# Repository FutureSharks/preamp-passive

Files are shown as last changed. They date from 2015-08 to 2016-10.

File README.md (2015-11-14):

# Preamp - Passive

This is the Arduino code, PCB layouts and 3D drawings for a HiFi passive preamplifier. It has the following features:

  * Volume control and input selection via encoder and Apple remote.
  * Uses a 256 step R2R relayed based attenuator.
  * Completely passive.
  * Only 5V power required.
  * [Adafruit NeoPixel](http://www.adafruit.com/category/168) shows volume level with colour.
  * Sleep mode with low power consumption: 0.9W.

Full build details can be found here:
http://www.diyaudio.com/forums/analog-line-level/275446-passive-preamp-arduino-based-remote-control-relay-r2r-input-selection.html

## Hardware

  * [MCP23S17](http://www.microchip.com/wwwproducts/Devices.aspx?product=MCP23S17): Controlled via SPI. This is the R2R relayed attenuator and controls the volume.
  * [MCP23S08](http://www.microchip.com/wwwproducts/Devices.aspx?product=MCP23S08): Controlled via SPI. For the input selector and mute.
  * [Adafruit NeoPixel](http://www.adafruit.com/category/168): Controlled via a single-wire control protocol.
  * IR sensor: Standard 38Khz type.
  * [Bourns EM14](https://www.bourns.com/pdfs/em14.pdf) Rotary Optical Encoder with switch.
  * [Modushop Galaxy Maggiorato GX187](http://www.modu.it/galaxyeng.html) with custom machined front and rear.

PCB and schematics are provided in EAGLE PCB format.

Front and rear panel 3D drawings are in AutoCAD format.

The IRremote library is from here:
https://github.com/z3t0/Arduino-IRremote

Adafruit NeoPixel library is from here:
https://github.com/adafruit/Adafruit_NeoPixel

## Photos

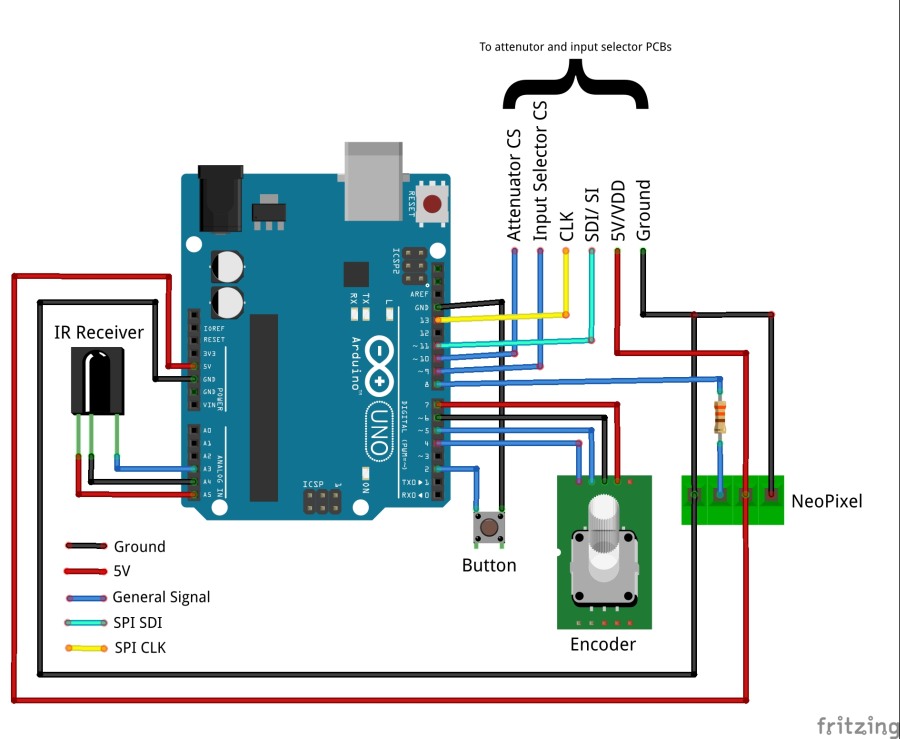
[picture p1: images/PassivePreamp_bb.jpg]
Connection diagram


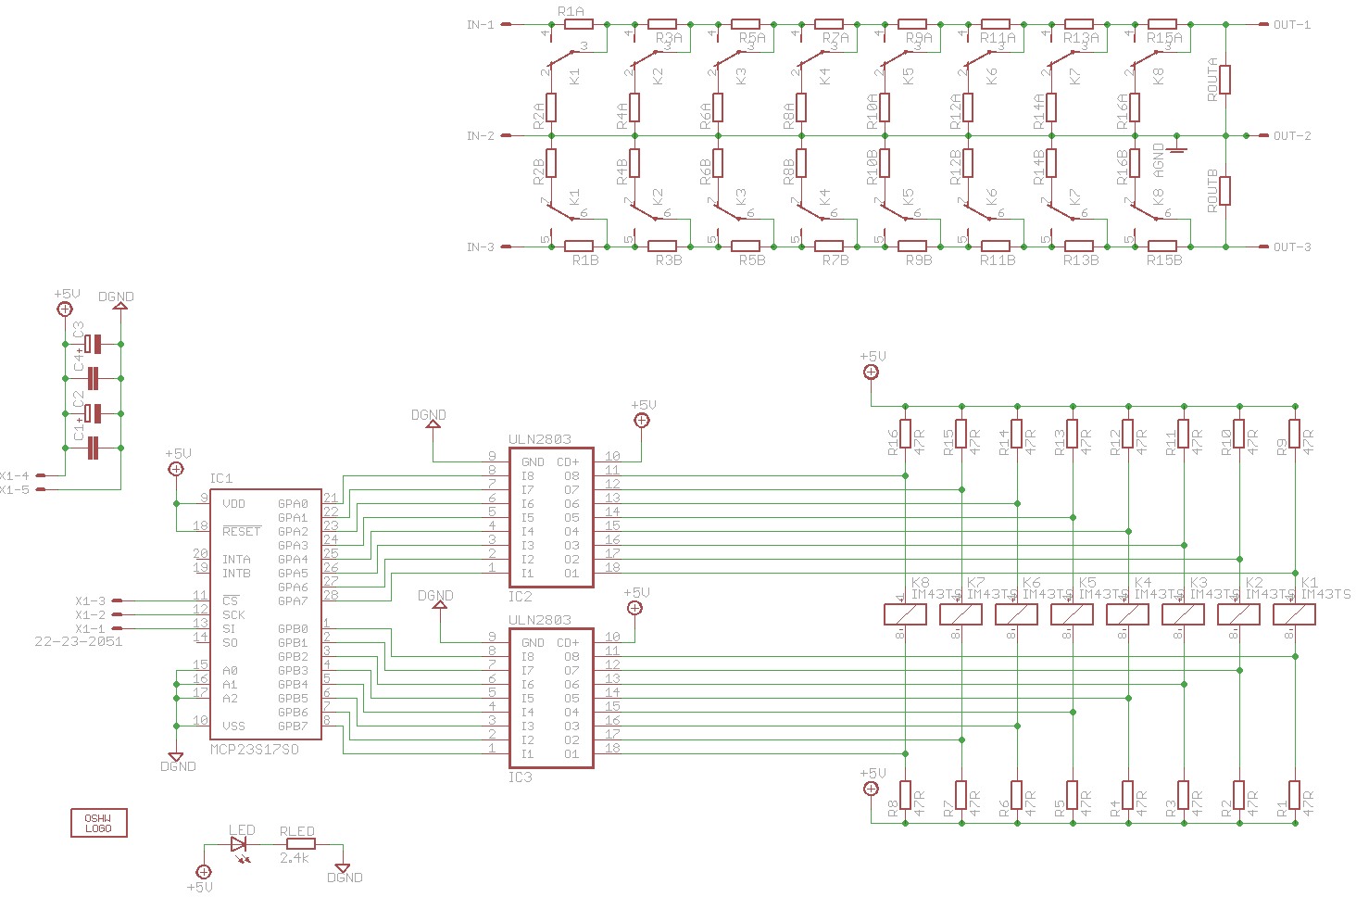
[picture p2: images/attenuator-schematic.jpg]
Attenuator schematic


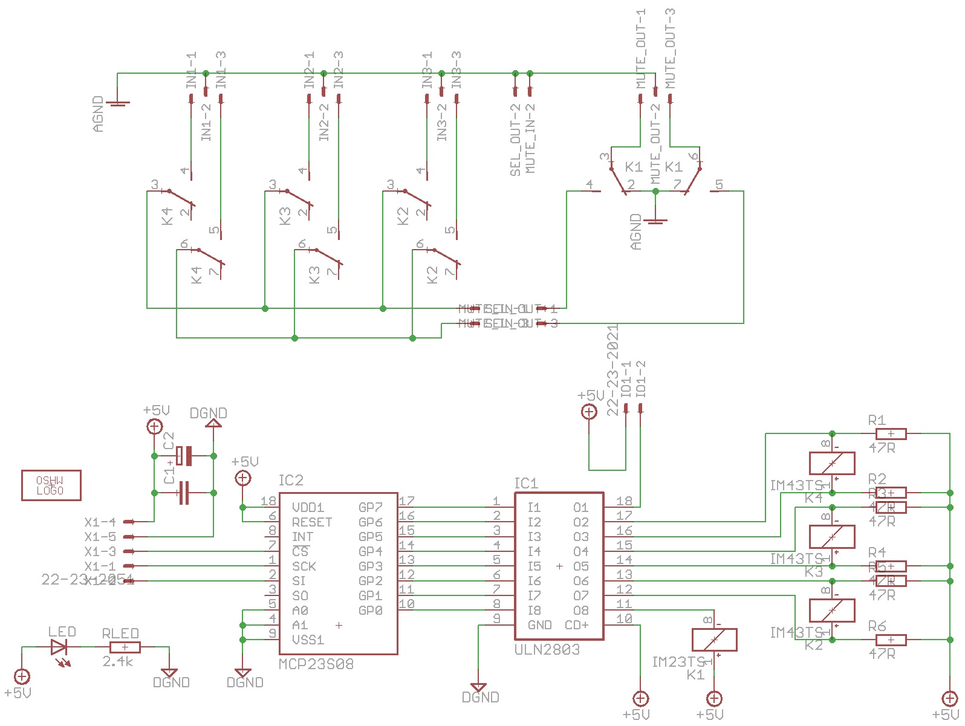
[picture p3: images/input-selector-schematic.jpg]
Input selector schematic


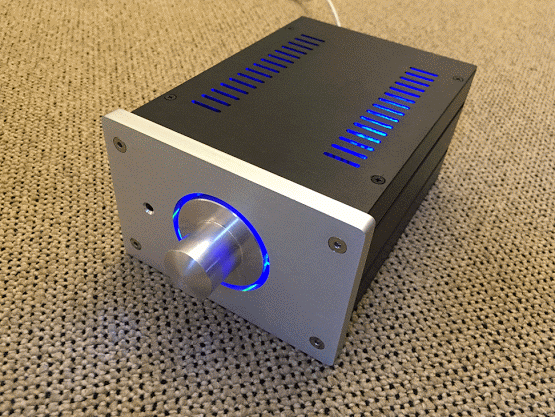
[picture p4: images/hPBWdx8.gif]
Completed preamp GIF


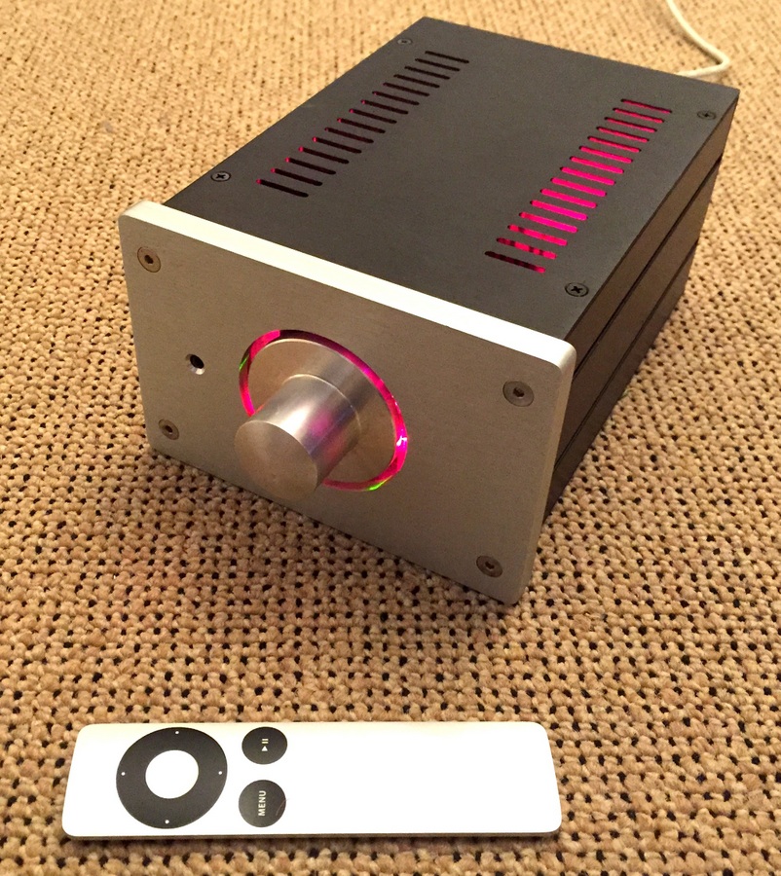
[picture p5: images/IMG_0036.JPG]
Completed preamp 1


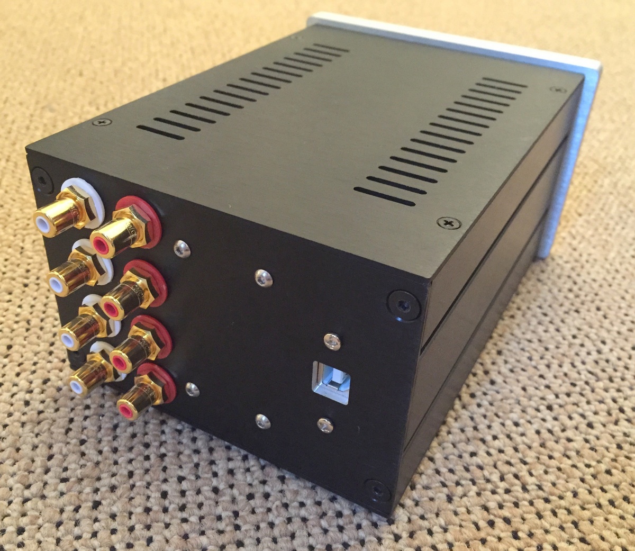
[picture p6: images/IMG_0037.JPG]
Completed preamp 2


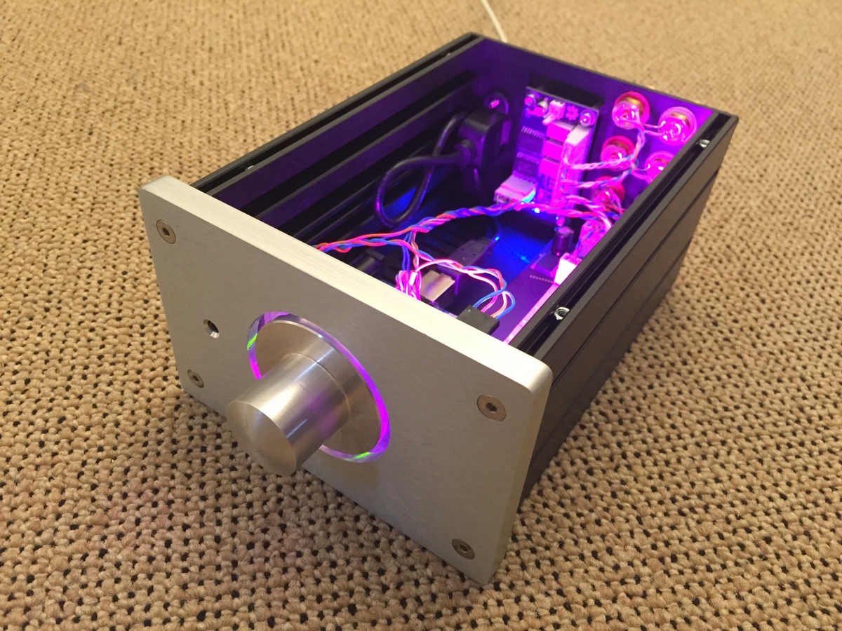
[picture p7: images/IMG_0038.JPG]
Completed preamp 3


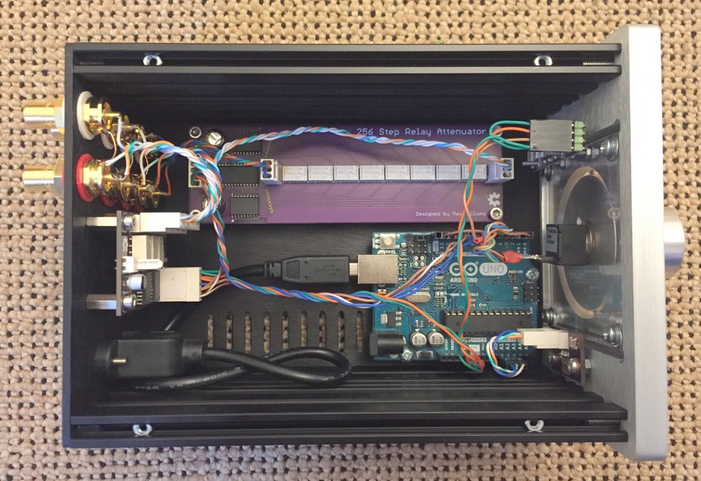
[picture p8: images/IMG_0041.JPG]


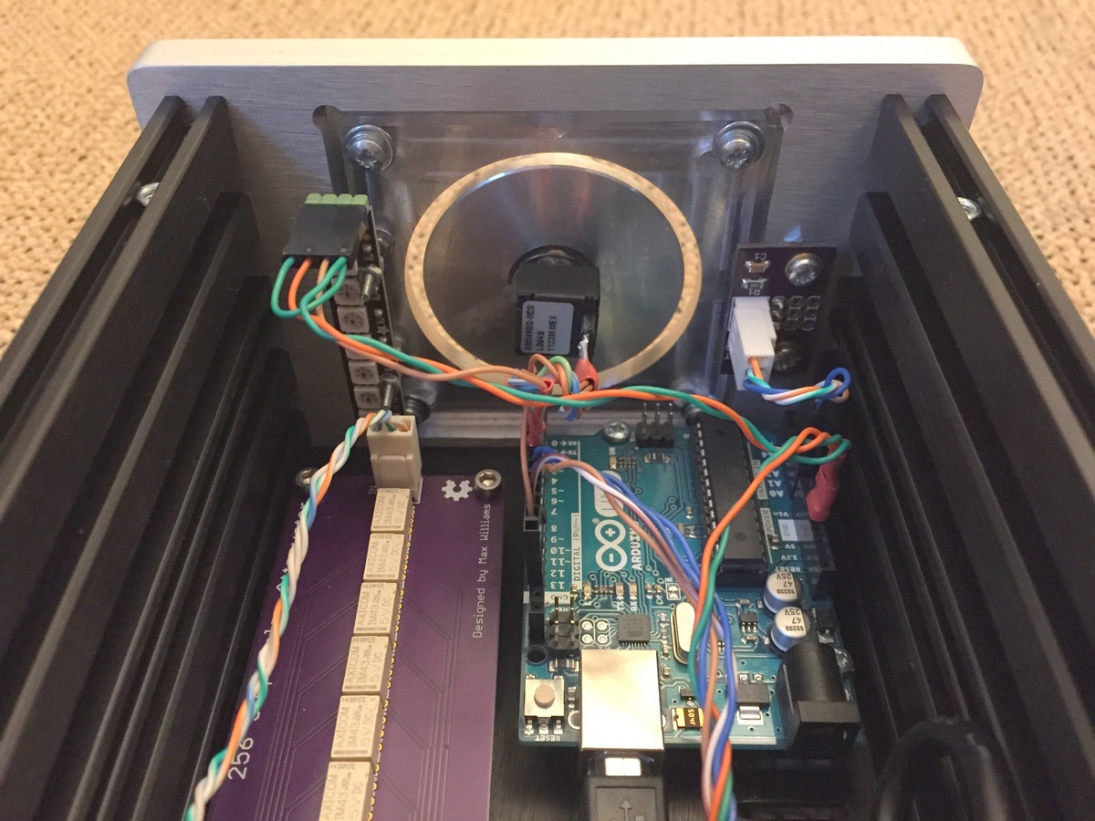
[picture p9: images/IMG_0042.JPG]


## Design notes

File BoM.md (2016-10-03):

| Part name | Farnell Part | Description | Notes | Quantity | Price | Total |
|---|---|---|---|---|---|---|
| IC1 | 1332093 | MCP23S17-E/SO | | 1 | | |
| IC2-3 | 1652419 | ULN2803ADW | | 3 | | |
| K1-8 | 1770588 | IM43TS or IM42TS | | 8 | | |
| PCB | - | From OSHPark | | 1 | £9.10 | |
| R1-16 | 2332121 | TE CONNECTIVITY - CRGH1206F47R | | 16 | £0.02 | £0.32 |
| | 2332121 | Description: RESISTOR, POWER, 47R, 0.5W, 1%, 1206 | | | | |
| C2-3 | 1800604 | EEUFR0J821 | | 2 | | |
| | | PANASONIC EEUFR0J821-CAP, ALU ELEC, 820UF, 6.3V, RAD | | | | |
| C1, C4 | Any | CAPACITOR, 1206, 100-220NF, 50V, X7R | | 2 | | |
| LED | Any | 1206 LED | | 1 | | |
| RLED | Any | Resistor for LED | | 1 | | |
| IN, OUT | 1675765 | MULTICOMP - MC34631 | | 2 | £0.20 | £0.40 |
| | | Description: HEADER, THT, VERTICAL, 2.54MM, 3WAY | | | | |
| X1 | 1675767 | MULTICOMP - MC34655 | | 1 | £0.36 | £0.36 |
| | | Description: HEADER, SQUARE PIN, 2.54MM, 5WAY | | | | |
| | | | | | | |
| R1 | | 560 | Value for 10K attenuator | 2 | | |
| R2 | | 160000 | Value for 10K attenuator | 2 | | |
| R3 | | 1100 | Value for 10K attenuator | 2 | | |
| R4 | | 82000 | Value for 10K attenuator | 2 | | |
| R5 | | 2000 | Value for 10K attenuator | 2 | | |
| R6 | | 39000 | Value for 10K attenuator | 2 | | |
| R7 | | 3600 | Value for 10K attenuator | 2 | | |
| R8 | | 16000 | Value for 10K attenuator | 2 | | |
| R9 | | 6200 | Value for 10K attenuator | 2 | | |
| R10 | | 6800 | Value for 10K attenuator | 2 | | |
| R11 | | 8200 | Value for 10K attenuator | 2 | | |
| R12 | | 1800 | Value for 10K attenuator | 2 | | |
| R13 | | 10000 | Value for 10K attenuator | 2 | | |
| R14 | | 270 | Value for 10K attenuator | 2 | | |
| R15 | | 10000 | Value for 10K attenuator | 2 | | |
| R16 | | 6.2 | Value for 10K attenuator | 2 | | |
| Rout | | 10000 | Value for 10K attenuator | 2 | | |

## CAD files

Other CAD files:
cad/small-preamp-front.dwg
cad/small-preamp-rear.dwg

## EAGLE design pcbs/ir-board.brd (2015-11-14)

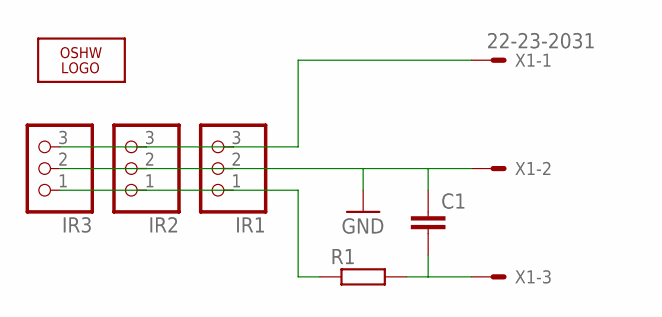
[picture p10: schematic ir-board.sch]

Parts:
C1: C-EUC1206; C1206
IR1, IR2, IR3: PINHD-1X3; 1X03
LOGO1: OSHW_LOGO_6MILX0200-NT; OSHW_6X200_NOTEXT
R1: R-EU_R1206; R1206
X1: 22-23-2031

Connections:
GND: C1.1, IR1.2, IR2.2, IR3.2, X1.2
unnamed: C1.2, R1.2, X1.3
OUT: IR1.3, IR2.3, IR3.3, X1.1
VS: IR1.1, IR2.1, IR3.1, R1.1

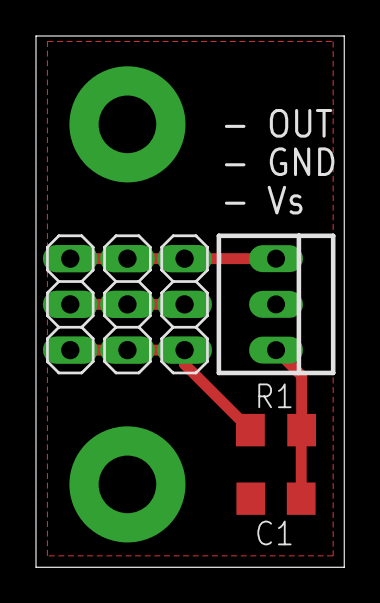
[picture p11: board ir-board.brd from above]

Board: 2 copper layers, 17.1 x 29.5 mm, 7 parts (1 on the bottom side), 4 nets.

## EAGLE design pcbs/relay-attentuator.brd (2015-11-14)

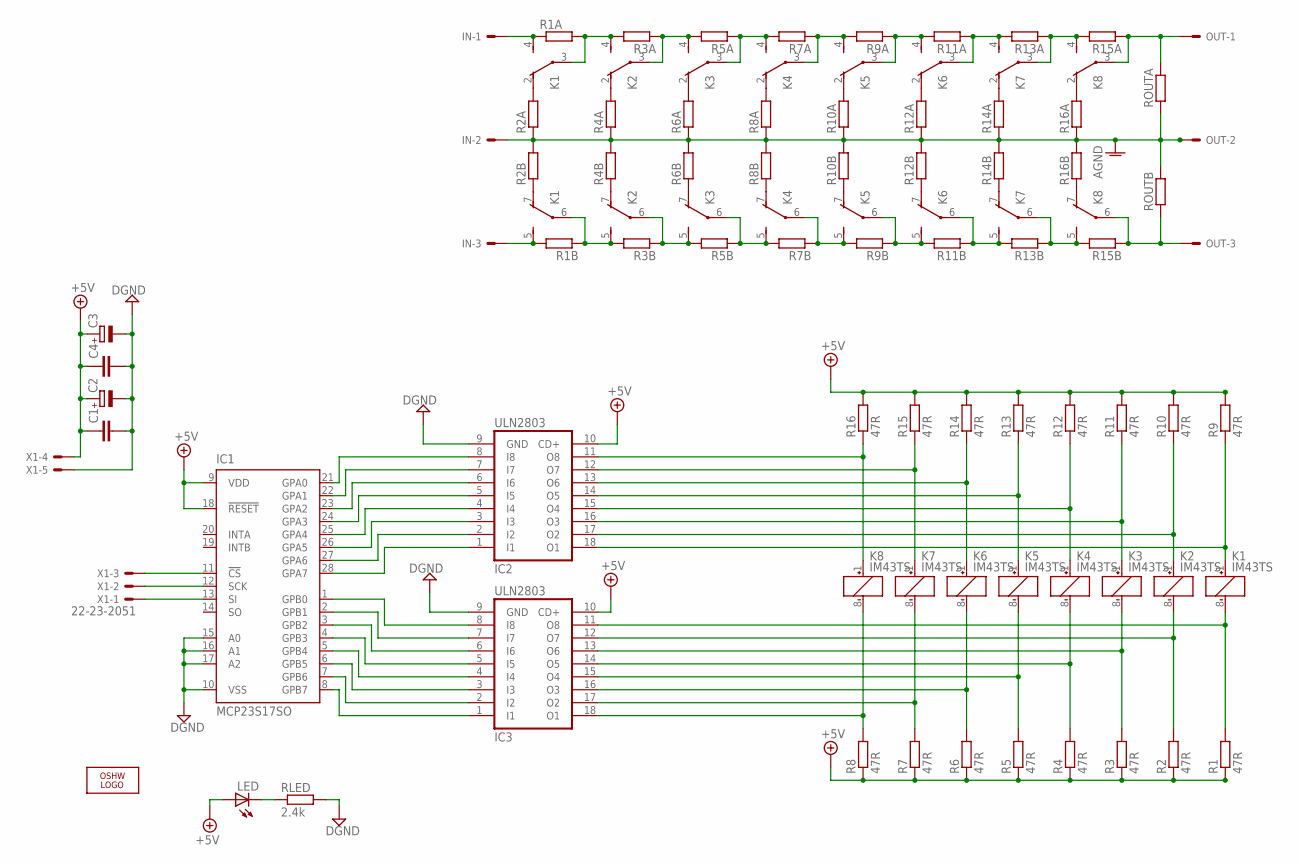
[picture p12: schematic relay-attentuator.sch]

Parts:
C1, C4: C-EUC1206; C1206
C2, C3: CPOL-EUE3.5-8; E3,5-8
IC1: MCP23S17SO; SO28W
IC2, IC3: ULN2803; SO-18W
IN: 22-23-2031
K1, K2, K3, K4, K5, K6, K7, K8: IM43TS
LED: LEDCHIPLED_1206; CHIPLED_1206
LOGO1: OSHW_LOGO_FILLX0200-NT; OSHW_FILLX200_NOTEXT
OUT: 22-23-2031
R1, R2, R3, R4, R5, R6, R7, R8, R9, R10, R11, R12, R13, R14, R15, R16: 47R; R1206
R1A, R1B, R2A, R2B, R3A, R3B, R4A, R4B, R5A, R5B, R6A, R6B, R7A, R7B, R8A, R8B, R9A, R9B, R10A, R10B, R11A, R11B, R12A, R12B, R13A, R13B, R14A, R14B, R15A, R15B, R16A, R16B: R-EU_R1206; R1206
RLED: 2.4k; R1206
ROUTA: R-EU_R1206; R1206
ROUTB: R-EU_R1206; R1206
X1: 22-23-2051

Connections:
+5V: C1.1, C2.+, C3.+, C4.1, IC1.9 (VDD), IC1.18 (!RESET), IC2.10 (CD+), IC3.10 (CD+), LED.A, R1.1, R2.1, R3.1, R4.1, R5.1, R6.1, R7.1, R8.1, R9.2, R10.2, R11.2, R12.2, R13.2, R14.2, R15.2, R16.2, X1.4
AGND: IN.2, OUT.2, R2A.1, R2B.2, R4A.1, R4B.2, R6A.1, R6B.2, R8A.1, R8B.2, R10A.1, R10B.2, R12A.1, R12B.2, R14A.1, R14B.2, R16A.1, R16B.2, ROUTA.1, ROUTB.2
ATT_INL: IN.1, K1.4 (S), R1A.1
ATT_INR: IN.3, K1.5 (S), R1B.2
CS: IC1.11 (!CS), X1.3
DGND: C1.2, C2.-, C3.-, C4.2, IC1.10 (VSS), IC1.15 (A0), IC1.16 (A1), IC1.17 (A2), IC2.9 (GND), IC3.9 (GND), RLED.2, X1.5
unnamed: IC2.11 (O8), K8.1 (+), R16.1
unnamed: IC3.11 (O8), K1.8 (-), R1.2
unnamed: IC3.17 (O2), K7.8 (-), R7.2
unnamed: IC3.13 (O6), K3.8 (-), R3.2
unnamed: IC3.14 (O5), K4.8 (-), R4.2
unnamed: K2.7 (O), R4B.1
unnamed: K1.7 (O), R2B.1
unnamed: K1.2 (O), R2A.2
unnamed: IC3.18 (O1), K8.8 (-), R8.2
unnamed: IC2.12 (O7), K7.1 (+), R15.1
unnamed: IC2.13 (O6), K6.1 (+), R14.1
unnamed: IC2.14 (O5), K5.1 (+), R13.1
unnamed: IC2.15 (O4), K4.1 (+), R12.1
unnamed: IC2.16 (O3), K3.1 (+), R11.1
unnamed: IC2.17 (O2), K2.1 (+), R10.1
unnamed: IC2.18 (O1), K1.1 (+), R9.1
unnamed: K3.7 (O), R6B.1
unnamed: IC3.12 (O7), K2.8 (-), R2.2
unnamed: IC3.16 (O3), K6.8 (-), R6.2
unnamed: IC3.15 (O4), K5.8 (-), R5.2
unnamed: K4.7 (O), R8B.1
unnamed: K5.7 (O), R10B.1
unnamed: K6.7 (O), R12B.1
unnamed: K7.7 (O), R14B.1
unnamed: K8.7 (O), R16B.1
unnamed: K2.2 (O), R4A.2
unnamed: K3.2 (O), R6A.2
unnamed: K4.2 (O), R8A.2
unnamed: K5.2 (O), R10A.2
unnamed: K6.2 (O), R12A.2
unnamed: K7.2 (O), R14A.2
unnamed: K8.2 (O), R16A.2
unnamed: IC1.28 (GPA7), IC2.1 (I1)
unnamed: IC1.27 (GPA6), IC2.2 (I2)
unnamed: IC1.26 (GPA5), IC2.3 (I3)
unnamed: IC1.25 (GPA4), IC2.4 (I4)
unnamed: IC1.24 (GPA3), IC2.5 (I5)
unnamed: IC1.23 (GPA2), IC2.6 (I6)
unnamed: IC1.22 (GPA1), IC2.7 (I7)
unnamed: IC1.21 (GPA0), IC2.8 (I8)
unnamed: IC1.8 (GPB7), IC3.1 (I1)
unnamed: IC1.7 (GPB6), IC3.2 (I2)
unnamed: IC1.6 (GPB5), IC3.3 (I3)
unnamed: IC1.5 (GPB4), IC3.4 (I4)
unnamed: IC1.4 (GPB3), IC3.5 (I5)
unnamed: IC1.3 (GPB2), IC3.6 (I6)
unnamed: IC1.2 (GPB1), IC3.7 (I7)
unnamed: IC1.1 (GPB0), IC3.8 (I8)
unnamed: K7.6, K8.5 (S), R13B.1, R15B.2
unnamed: K7.3, K8.4 (S), R13A.1, R15A.2
unnamed: K6.6, K7.5 (S), R11B.1, R13B.2
unnamed: LED.C, RLED.1
unnamed: K8.6, OUT.3, R15B.1, ROUTB.1
unnamed: K8.3, OUT.1, R15A.1, ROUTA.2
unnamed: K1.3, K2.4 (S), R1A.2, R3A.2
unnamed: K2.3, K3.4 (S), R3A.1, R5A.2
unnamed: K1.6, K2.5 (S), R1B.1, R3B.2
unnamed: K3.3, K4.4 (S), R5A.1, R7A.2
unnamed: K4.3, K5.4 (S), R7A.1, R9A.2
unnamed: K5.3, K6.4 (S), R9A.1, R11A.2
unnamed: K6.3, K7.4 (S), R11A.1, R13A.2
unnamed: K2.6, K3.5 (S), R3B.1, R5B.2
unnamed: K3.6, K4.5 (S), R5B.1, R7B.2
unnamed: K4.6, K5.5 (S), R7B.1, R9B.2
unnamed: K5.6, K6.5 (S), R9B.1, R11B.2
SCK: IC1.12 (SCK), X1.2
SI: IC1.13 (SI), X1.1

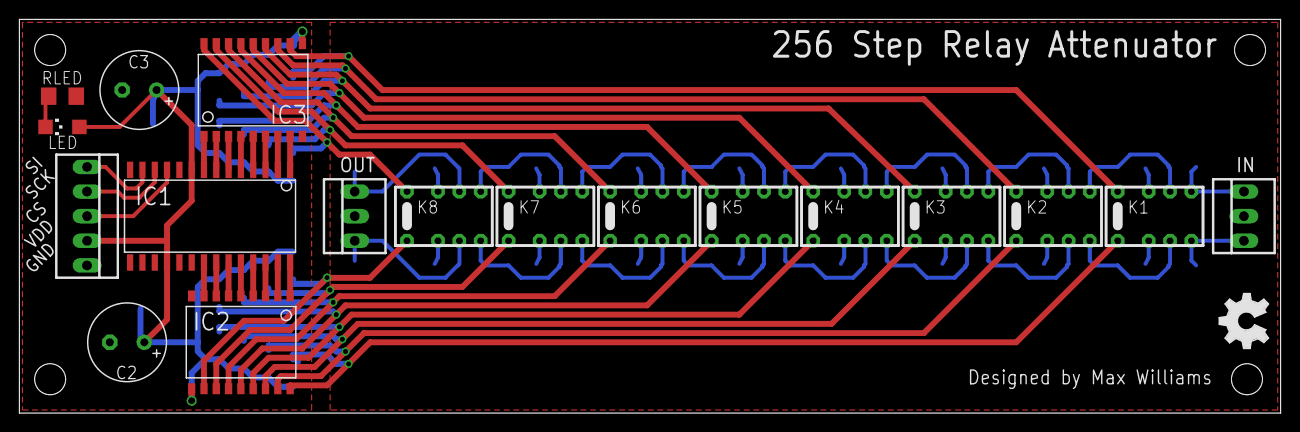
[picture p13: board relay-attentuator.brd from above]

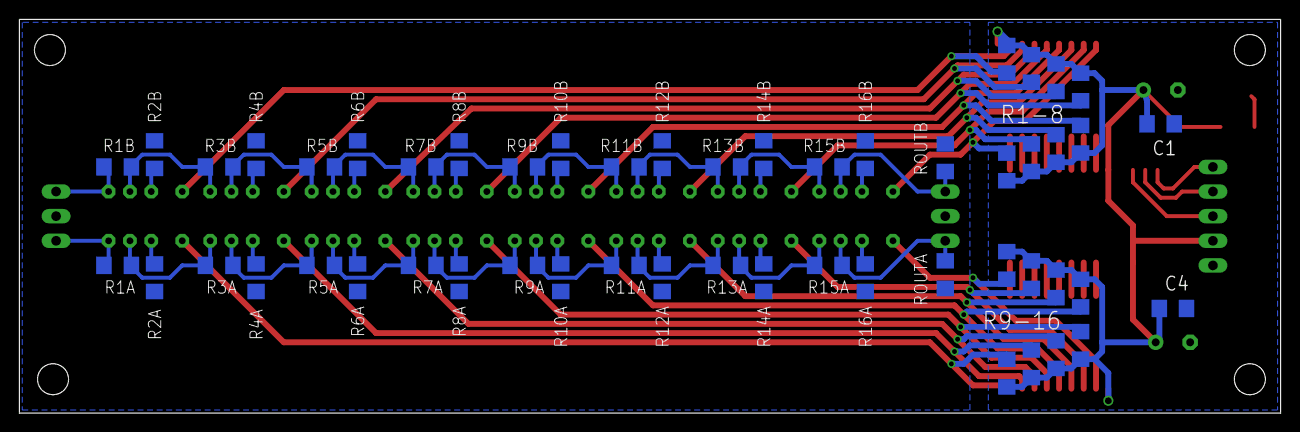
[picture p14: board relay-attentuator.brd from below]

Board: 2 copper layers, 130.2 x 40.6 mm, 71 parts (52 on the bottom side), 73 nets.

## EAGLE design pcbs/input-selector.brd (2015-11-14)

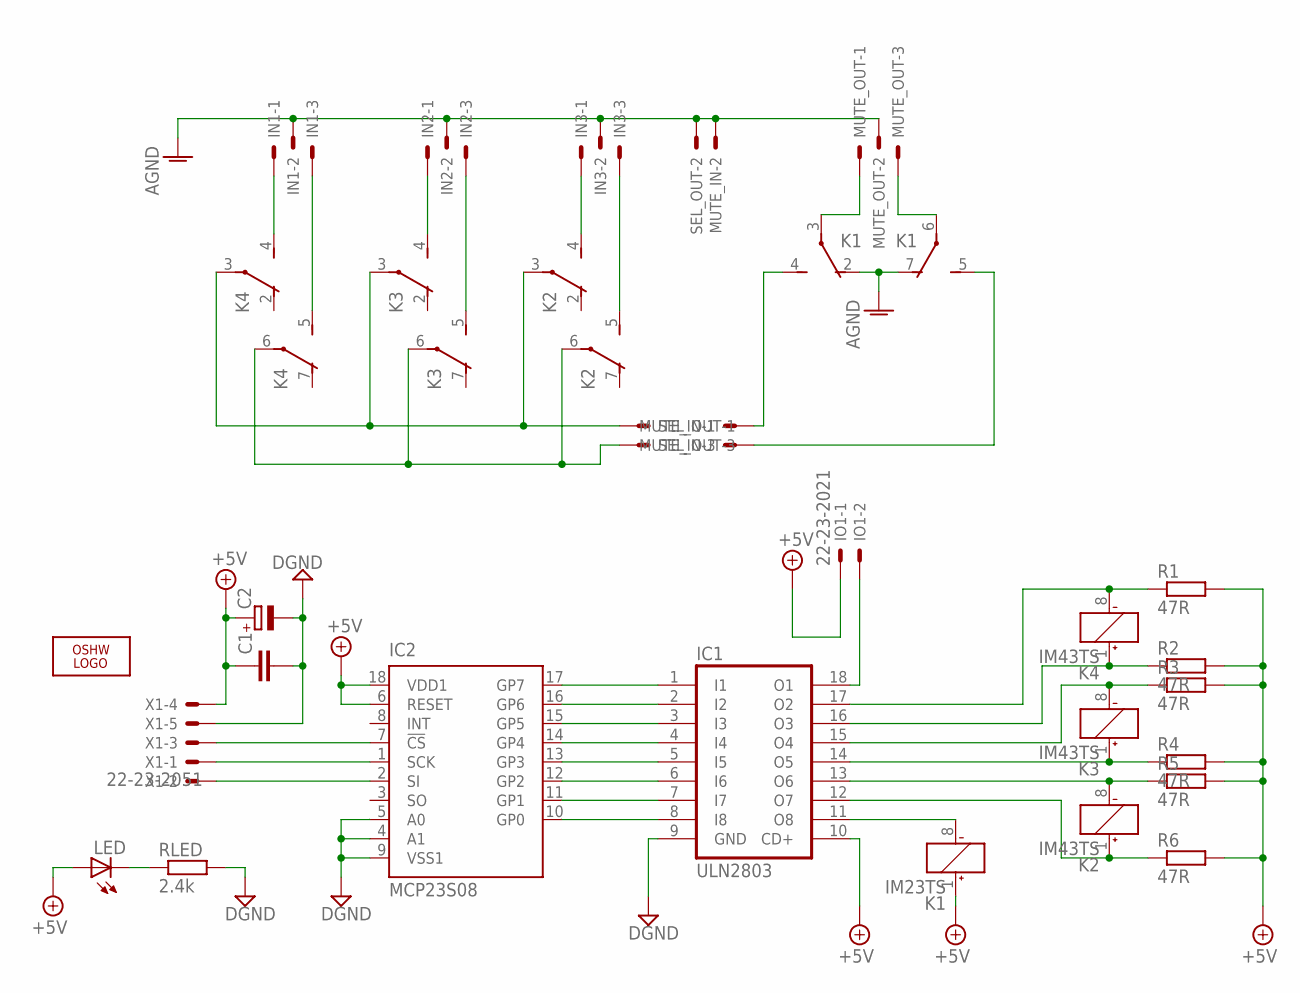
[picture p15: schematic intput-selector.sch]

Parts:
C1: C-EUC1206; C1206
C2: CPOL-EUC; PANASONIC_C
IC1: ULN2803; SO-18W
IC2: MCP23S08; SO-18W
IN1, IN2, IN3: 22-23-2031
IO1: 22-23-2021
K1: IM23TS; IM43TS
K2, K3, K4: IM43TS
LED: LEDCHIPLED_1206; CHIPLED_1206
LOGO1: OSHW_LOGO_FILLX0200-NT; OSHW_FILLX200_NOTEXT
MUTE_IN: 22-23-2031
MUTE_OUT: 22-23-2031
R1, R2, R3, R4, R5, R6: 47R; R1206
RLED: 2.4k; R1206
SEL_OUT: 22-23-2031
X1: 22-23-2051

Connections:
+5V: C1.1, C2.+, IC1.10 (CD+), IC2.6 (RESET), IC2.18 (VDD1), IO1.1, K1.1 (+), LED.A, R1.2, R2.2, R3.2, R4.2, R5.2, R6.2, X1.4
AGND: IN1.2, IN2.2, IN3.2, K1.2 (O), K1.7 (O), MUTE_IN.2, MUTE_OUT.2, SEL_OUT.2
CS: IC2.7 (!CS), X1.3
DGND: C1.2, C2.-, IC1.9 (GND), IC2.4 (A1), IC2.5 (A0), IC2.9 (VSS1), RLED.2, X1.5
INL: K2.3, K3.3, K4.3, SEL_OUT.1
INR: K2.6, K3.6, K4.6, SEL_OUT.3
unnamed: IC1.1 (I1), IC2.17 (GP7)
unnamed: IC1.2 (I2), IC2.16 (GP6)
unnamed: IC1.3 (I3), IC2.15 (GP5)
unnamed: IC1.5 (I5), IC2.13 (GP3)
unnamed: IC1.6 (I6), IC2.12 (GP2)
unnamed: IC1.7 (I7), IC2.11 (GP1)
unnamed: IC1.4 (I4), IC2.14 (GP4)
unnamed: IC1.8 (I8), IC2.10 (GP0)
unnamed: IC1.16 (O3), K4.1 (+), R2.1
unnamed: IC1.14 (O5), K3.1 (+), R4.1
unnamed: IC1.13 (O6), K2.8 (-), R5.1
unnamed: IC1.12 (O7), K2.1 (+), R6.1
unnamed: IC1.15 (O4), K3.8 (-), R3.1
unnamed: IC1.11 (O8), K1.8 (-)
unnamed: IC1.17 (O2), K4.8 (-), R1.1
unnamed: IC1.18 (O1), IO1.2
unnamed: K1.6, MUTE_OUT.3
unnamed: K1.3, MUTE_OUT.1
unnamed: IN1.1, K4.4 (S)
unnamed: IN1.3, K4.5 (S)
unnamed: IN2.1, K3.4 (S)
unnamed: IN2.3, K3.5 (S)
unnamed: IN3.1, K2.4 (S)
unnamed: IN3.3, K2.5 (S)
unnamed: LED.C, RLED.1
OUTL: K1.4 (S), MUTE_IN.1
OUTR: K1.5 (S), MUTE_IN.3
SCK: IC2.1 (SCK), X1.1
SI: IC2.2 (SI), X1.2

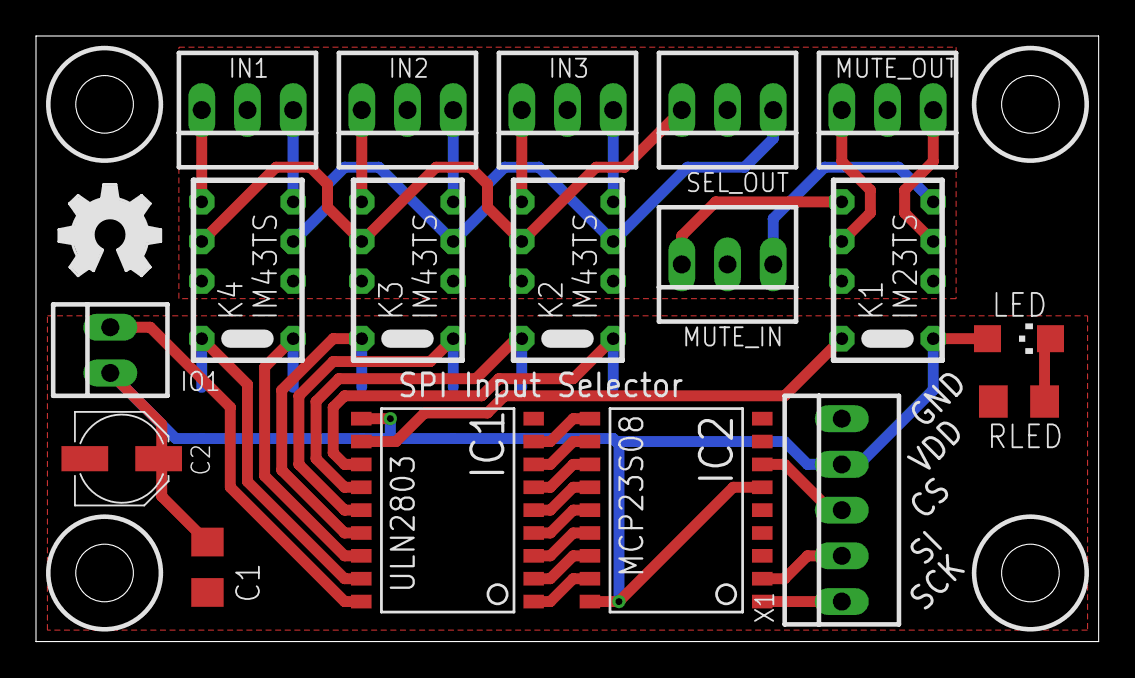
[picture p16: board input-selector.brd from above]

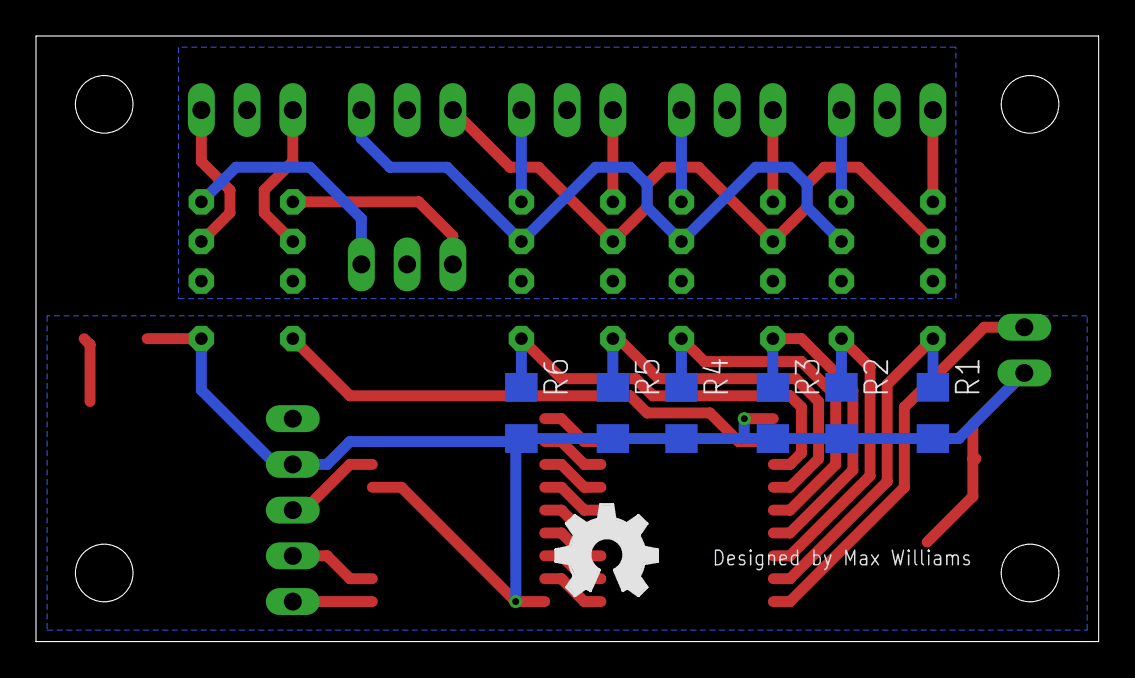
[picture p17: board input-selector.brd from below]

Board: 2 copper layers, 59.0 x 33.6 mm, 26 parts (7 on the bottom side), 35 nets.

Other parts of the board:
LOGO2: OSHW_LOGO_FILLX0200-NT; OSHW_FILLX200_NOTEXT

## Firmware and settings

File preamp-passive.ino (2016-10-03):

///////////////////////////////////////////////////////////////////////////////////////////////////////////////////////////////////////
// To do:
//
///////////////////////////////////////////////////////////////////////////////////////////////////////////////////////////////////////

// If enabled volume/input data will be printed via serial
bool debugEnabled = false;

// EEPROM related stuff to save volume level
//#include "EEPROM.h"
//int dBLevelEEPROMAddressBit = 0;
//bool isVolumeSavedToEeprom = true;
//unsigned long timeOfLastVolumeChange;
//unsigned long timeBetweenVolumeSaves = 60000;
//float maximumLevelToSave = -30.0;
//float currentSavedDbLevel;

// SPI library
#include "SPI.h"
// Arduino pin 9 & 10 = Input selector & Relay attenuator
// Arduino pin 11 = SDI
// Arduino pin 13 = CLK

// IR stuff
#include "IRremote.h"
int RECV_PIN = A3;  // IR Receiver pin
const int IRGroundPin = A4;
const int IRPowerPin = A5;
IRrecv irrecv(RECV_PIN);
decode_results results;
String lastIRoperation;
float iRIncrement = 5;
unsigned long timeOfLastIRChange;

// NeoPixel stuff
#include "Adafruit_NeoPixel.h"
const int NeoPixelPin = 8;
Adafruit_NeoPixel strip = Adafruit_NeoPixel(60, NeoPixelPin, NEO_GRB + NEO_KHZ800);
unsigned long timeOfLastNeopixelColourChange;
byte NeoPixelRed;
byte NeoPixelGreen;
byte NeoPixelBlue;

// Input selector stuff
int selectedInput = 0;
const int inputSelectorCSPin = 9;
long muteDelay = 1000;

// Relay attenuator stuff
const int AttenuatorCSPin = 10;
byte currentAttenuatorLevel = 30;
bool muteEnabled = false;
byte lastAttenuatorLevel;

// Encoder stuff
const int encoder0GroundPin = 6;
const int encoder0PowerPin = 7;
int encoder0PinA = 5;
int encoder0PinB = 4;
int encoder0Pos = 0;
int encoder0PinALast = HIGH;
int n = LOW;
float encoderIncrement = 2;

// Button stuff
const int buttonPin = 2;

// System stuff
unsigned long timeOfLastOperation;
unsigned long timeToSleep = 120000;
bool sleeping;

//////////////////////////////////////////////////////////////////////////////////////////////
// Setup
//////////////////////////////////////////////////////////////////////////////////////////////
void setup() {
  // Serial
  if (debugEnabled) {
    Serial.begin (9600);
  }
  // SPI
  // set the CS pins as output:
  pinMode (inputSelectorCSPin, OUTPUT);
  digitalWrite(inputSelectorCSPin,HIGH);
  pinMode (AttenuatorCSPin, OUTPUT);
  digitalWrite(AttenuatorCSPin,HIGH);
  // Start SPI
  if (debugEnabled) {
    Serial.println ("Starting SPI..");
  }
  SPI.begin();
  // Set SPI selector IO direction to output for all pinds
  if (debugEnabled) {
    Serial.println ("Setting SPI selector IO direction control registers..");
  }
  digitalWrite(inputSelectorCSPin,LOW);
  SPI.transfer(B01000000); // Send Device Opcode
  SPI.transfer(0); // Select IODIR register
  SPI.transfer(0); // Set register
  digitalWrite(inputSelectorCSPin,HIGH);
  // Set up pins for encoder:
  pinMode (encoder0PinA,INPUT);
  pinMode (encoder0PinB,INPUT);
  pinMode (encoder0GroundPin,OUTPUT);
  pinMode (encoder0PowerPin,OUTPUT);
  digitalWrite(encoder0GroundPin,LOW);
  digitalWrite(encoder0PowerPin,HIGH);
  // IR
  irrecv.enableIRIn(); // Start the receiver
  pinMode(IRPowerPin, OUTPUT);
  pinMode(IRGroundPin, OUTPUT);
  digitalWrite(IRPowerPin, HIGH); // Power for the IR
  digitalWrite(IRGroundPin, LOW); // GND for the IR
  // NeoPixel
  strip.begin();
  // Buton setup
  pinMode (buttonPin, INPUT_PULLUP);
  // Attenuator setup
  // Set IO direction to output for all bank 0 (I/O pins 0-7)
  digitalWrite(AttenuatorCSPin,LOW);
  SPI.transfer(B01000000); // Send Device Opcode
  SPI.transfer(0);         // Select IODIR register for bank 0
  SPI.transfer(0);         // Set register
  digitalWrite(AttenuatorCSPin,HIGH);
  // Set IO direction to output for all bank 1 (I/O pins 8-17)
  digitalWrite(AttenuatorCSPin,LOW);
  SPI.transfer(B01000000); // Send Device Opcode
  SPI.transfer(1);         // Select IODIR register for bank 1
  SPI.transfer(0);         // Set register
  digitalWrite(AttenuatorCSPin,HIGH);
  // Set inital attenuator level
  setAttenuatorLevel(currentAttenuatorLevel);
}

//////////////////////////////////////////////////////////////////////////////////////////////
// Function to set NeoPixel colour to match current DAC level
int setNeoPixelColourFromAttenuator (int level) {
  byte redPixelColor = level;
  byte bluePixelColor = 255 - redPixelColor;
  setNeoPixelColour(redPixelColor, 0, bluePixelColor);
}
//////////////////////////////////////////////////////////////////////////////////////////////
// Function to multiple NeoPixels to a colour simultaneously
int setNeoPixelColour (byte Red, byte Green, byte Blue) {
  NeoPixelRed = Red;
  NeoPixelGreen = Green;
  NeoPixelBlue = Blue;
  strip.setPixelColor(0, Red, Green, Blue);
  strip.setPixelColor(1, Red, Green, Blue);
  strip.setPixelColor(2, Red, Green, Blue);
  strip.setPixelColor(3, Red, Green, Blue);
  strip.setPixelColor(4, Red, Green, Blue);
  strip.setPixelColor(5, Red, Green, Blue);
  strip.setPixelColor(6, Red, Green, Blue);
  strip.setPixelColor(7, Red, Green, Blue);
  strip.show();
}
//////////////////////////////////////////////////////////////////////////////////////////////
// Function to change to next input
int changeInput() {
  timeOfLastOperation = millis();
  sleeping = false;
  if (muteEnabled) { changeMute(); }
  selectedInput++;
  if (selectedInput > 3) { selectedInput = 1; }
  if (selectedInput < 1) { selectedInput = 3; }
  switch (selectedInput) {
    case 1:
      setMCP23Sxx(inputSelectorCSPin, 9, B01001011);
      delay(5);
      break;
    case 2:
      setMCP23Sxx(inputSelectorCSPin, 9, B00110011);
      delay(5);
      break;
    case 3:
      setMCP23Sxx(inputSelectorCSPin, 9, B00101101);
      delay(5);
      break;
  }
  setMCP23Sxx(inputSelectorCSPin, 9, B00000001);
  setNeoPixelColour(255, 0, 0);
  delay(40);
  setNeoPixelColour(0, 255, 0);
  delay(40);
  setNeoPixelColour(0, 0, 255);
  delay(40);
  setNeoPixelColourFromAttenuator(currentAttenuatorLevel);
  if (debugEnabled) {
    Serial.print ("Selected Input: ");
    Serial.println (selectedInput);
  }
}
//////////////////////////////////////////////////////////////////////////////////////////////
// Function to send data to the MCP23S17 (18 = GPIOA, 19 = GPIOB)
int setMCP23Sxx (int CSPin, int select_register, int register_value) {
  digitalWrite(CSPin,LOW);
  SPI.transfer(B01000000);
  SPI.transfer(select_register);
  SPI.transfer(register_value);
  digitalWrite(CSPin,HIGH);
}
//////////////////////////////////////////////////////////////////////////////////////////////
// Function to mirror and reverse a byte. This is used because the relays connected to one side of the setMCP23Sxx are reversed to the other.
int reverseAndMirrorByte (byte myByte) {
  byte myByteReversedAndMirrored;
  for (int reverseBit = 0; reverseBit < 8; reverseBit++) {
    if (bitRead(myByte, reverseBit) == 1) {
      bitWrite(myByteReversedAndMirrored, (7 - reverseBit), 0);
    } else {
      bitWrite(myByteReversedAndMirrored, (7 - reverseBit), 1);
    }
  }
  return myByteReversedAndMirrored;
}
//////////////////////////////////////////////////////////////////////////////////////////////
// Function to reverse a byte. This is used because the relays are connected to the setMCP23Sxx in reverse order.
int reverseByte (byte myByte) {
  byte myByteReversed;
  for (int reverseBit = 0; reverseBit < 8; reverseBit++) {
    if (bitRead(myByte, reverseBit) == 1) {
      bitWrite(myByteReversed, (7 - reverseBit), 1);
    } else {
      bitWrite(myByteReversed, (7 - reverseBit), 0);
    }
  }
  return myByteReversed;
}
//////////////////////////////////////////////////////////////////////////////////////////////
// Function to set a specific attenuator level
int setAttenuatorLevel (byte level) {
  muteEnabled = false;
  sleeping = false;
  currentAttenuatorLevel = level;
  if (debugEnabled) {
    Serial.print ("Attenuator Level: ");
    Serial.println (level);
  }
  byte real_level = 255 - level;
  byte gpioaValue = reverseByte(real_level);
  byte gpiobValue = reverseAndMirrorByte(gpioaValue);
  setMCP23Sxx(AttenuatorCSPin, 18, gpioaValue);
  setMCP23Sxx(AttenuatorCSPin, 19, gpiobValue);
  delay(1);
  setMCP23Sxx(AttenuatorCSPin, 18, B00000000);
  setMCP23Sxx(AttenuatorCSPin, 19, B00000000);
  // Set NeoPixel as well
  setNeoPixelColourFromAttenuator(level);
}
//////////////////////////////////////////////////////////////////////////////////////////////
// Functions to change volume
int changeVolume(int increment) {
  timeOfLastOperation = millis();
  sleeping = false;
  if (muteEnabled) { changeMute(); }
  int newAttenuatorLevel = currentAttenuatorLevel + increment;
  if (newAttenuatorLevel <= 255 && newAttenuatorLevel >= 0) {
    if (muteEnabled) { changeMute(); }
    setAttenuatorLevel(newAttenuatorLevel);
  } else if (newAttenuatorLevel > 255 && currentAttenuatorLevel != 255) {
    if (muteEnabled) { changeMute(); }
    setAttenuatorLevel(255);
  } else if (newAttenuatorLevel < 0 && currentAttenuatorLevel != 0) {
    setAttenuatorLevel(0);
  } else {
    if (debugEnabled) {
      Serial.println ("No volume change");
    }
  }
}
//////////////////////////////////////////////////////////////////////////////////////////////
// Function to change mute on input selector
int changeMute() {
  timeOfLastOperation = millis();
  sleeping = false;
  if (muteEnabled) {
    if (debugEnabled) {
      Serial.print ("Mute now disabled, setting volume to: ");
      Serial.println (lastAttenuatorLevel);
    }
    setAttenuatorLevel(lastAttenuatorLevel);
    muteEnabled = false;
  } else {
    lastAttenuatorLevel = currentAttenuatorLevel;
    setAttenuatorLevel(0);
    muteEnabled = true;
    if (debugEnabled) {
      Serial.println ("Mute enabled");
    }
  }
}
//////////////////////////////////////////////////////////////////////////////////////////////
// Main loop
//////////////////////////////////////////////////////////////////////////////////////////////
void loop() {
  // Read the encoder
  n = digitalRead(encoder0PinA);
  if ((encoder0PinALast == LOW) && (n == HIGH)) {
    if (digitalRead(encoder0PinB) == LOW) {
      changeVolume(-encoderIncrement);
    } else {
      changeVolume(encoderIncrement);
    }
  }
  encoder0PinALast = n;
  // Decode the IR if recieved
  if (irrecv.decode(&results)) {
    if (results.value == 2011287694) {
      lastIRoperation = "volumeUp";
      changeVolume(iRIncrement);
      timeOfLastIRChange = millis();
    }
    if (results.value == 2011279502) {
      lastIRoperation = "volumeDown";
      changeVolume(-iRIncrement);
      timeOfLastIRChange = millis();
    }
    if ((results.value == 2011291790) or (results.value == 2011238542)) {
      lastIRoperation = "changeInput";
      changeInput();
      delay(500);
      timeOfLastIRChange = millis();
    }
    if (results.value == 2011265678) {
      lastIRoperation = "playPause";
      changeMute();
      timeOfLastIRChange = millis();
    }
    if (results.value == 4294967295 && lastIRoperation != "None") {
      if (lastIRoperation == "volumeUp") { changeVolume(iRIncrement); timeOfLastIRChange = millis(); }
      if (lastIRoperation == "volumeDown") { changeVolume(-iRIncrement); timeOfLastIRChange = millis(); }
      if (lastIRoperation == "changeInput") { changeInput(); delay(500); timeOfLastIRChange = millis(); }
      timeOfLastIRChange = millis();
    }
    irrecv.resume(); // Receive the next value
  }
  // Read button state
  int buttonState = digitalRead(buttonPin);
  if (buttonState == LOW) {
    changeInput();
    delay(500);
  }
  // Set the time. This is used by other functions
  unsigned long currentTime = millis();
  // Stop IR repeating after timeout to stop interference from other remotes
  if ((currentTime - timeOfLastIRChange) > 1000 && lastIRoperation != "None") {
    lastIRoperation = "None";
  }
  // Fade out NeoPixel after a timeout
  if ((currentTime - timeOfLastOperation) > timeToSleep && !sleeping) {
    if (debugEnabled) { Serial.println ("Sleeping..."); }
    while ((NeoPixelRed + NeoPixelGreen + NeoPixelBlue) > 0) {
      if (NeoPixelRed > 0) { NeoPixelRed--; }
      if (NeoPixelGreen > 0) { NeoPixelGreen--; }
      if (NeoPixelBlue > 0) { NeoPixelBlue--; }
      setNeoPixelColour(NeoPixelRed, NeoPixelGreen, NeoPixelBlue);
      delay(5);
    }
    sleeping = true;
  }
}

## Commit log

2015-11-02 Removing bad debug serial.print statements.
2015-11-14 Adding license, more photos and PCB files.
    [input-selector.brd, intput-selector.sch, ir-board.brd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]
2015-11-14 Adding links to readme and add 3D drawings too.
    [small-preamp-front.dwg, small-preamp-rear.dwg]
2016-10-03 Adding BoM file
2016-10-03 Updating connection diagram
    [connection-diagram.fzz]
2016-10-03 Updating images
    [connection-diagram.fzz]
